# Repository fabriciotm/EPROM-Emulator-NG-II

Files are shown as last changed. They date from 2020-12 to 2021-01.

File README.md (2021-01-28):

# EPROM Emulator NG II

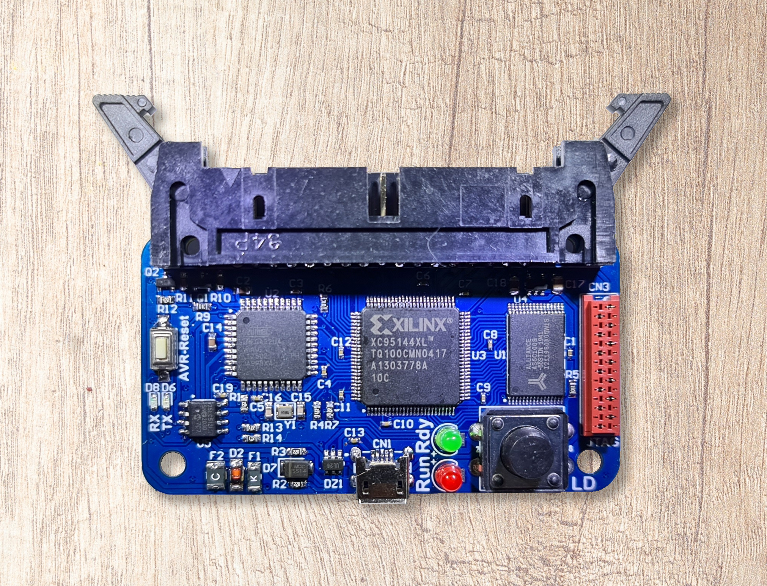
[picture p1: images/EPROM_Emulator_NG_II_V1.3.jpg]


## Introduction

Based on the project by Kris Sekula:

**GitHub**: https://github.com/Kris-Sekula/EPROM-EMU-NG

I developed a version where the TTL logic was replaced by a CPLD. This made the circuit much smaller. 

Instead of the Arduino Nano I directly integrated an ATMega32u4. This is flashed with the bootloader of the Arduino Micro (Using a simple ISP programmer). After that, the firmware can be flashed via USB at any time using the Arduino IDE.

## PCB

**PCB Version 1.3B**

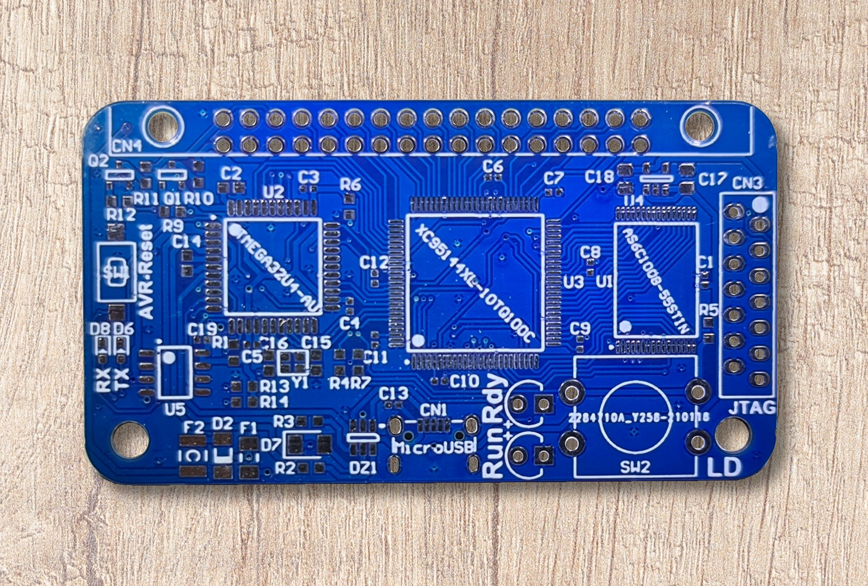
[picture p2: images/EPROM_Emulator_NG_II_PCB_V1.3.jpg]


Current version of the board.

## Assembly

The assembly is done from large to small. So first the biggest parts, like CPLD, ATMega, etc. are soldered on. Then in descending order the other parts, except the EEPROM. 

This should be soldered only after the bootloader for the ATMega has been flashed. Otherwise there can be problems with flashing.

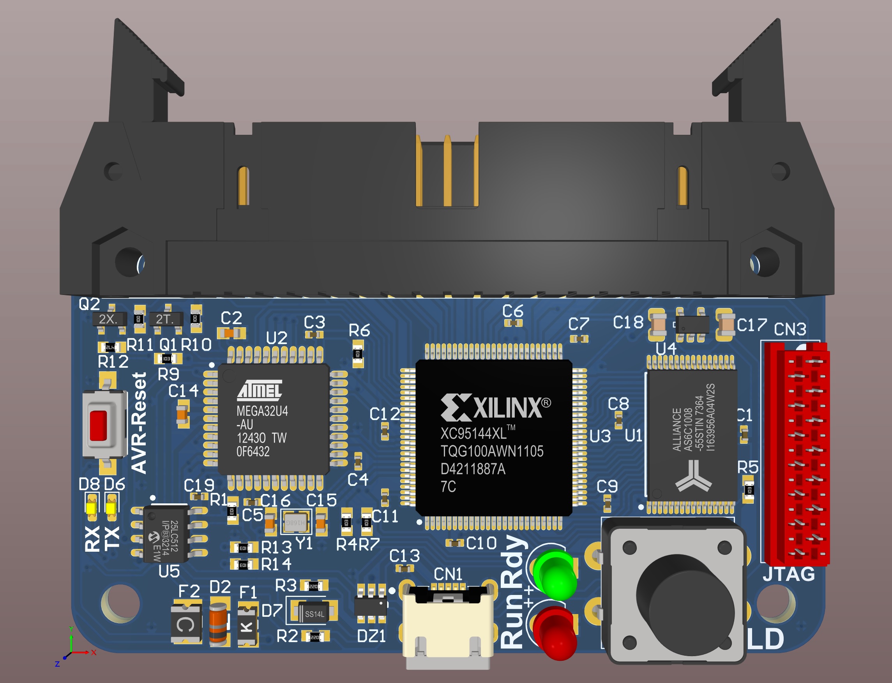
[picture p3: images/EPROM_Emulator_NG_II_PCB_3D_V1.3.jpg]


When all parts, except the EEPROM, are soldered, it goes to the flashing of the Arduino bootloader.

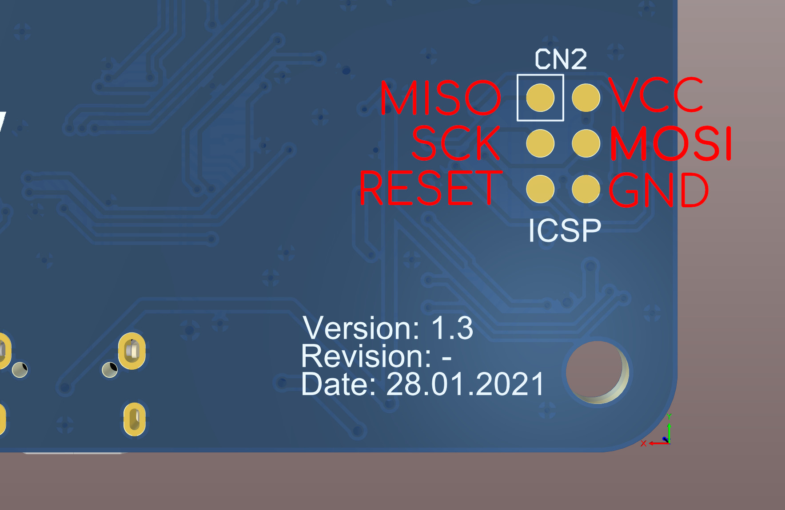
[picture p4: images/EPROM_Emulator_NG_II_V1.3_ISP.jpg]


For this purpose, there is a corresponding connector on the back. The easiest way to flash the bootloader is with Pogo PINs or a simple pin header, which are pressed onto the contacts.

A USBasp can be used for programming, for example.  And with the Arduino IDE the bootloader can then be uploaded.

It is important that the Arduino Micro is selected here.

If the bootloader has been installed successfully, the EEPROM can now be soldered on.

## Firmware flashing

First the EPROM Emulator NG II can be connected to the PC via USB. With the help of the Arduino IDE the ATMega is programmed first.

The current firmware can be found at https://github.com/Kris-Sekula/EPROM-EMU-NG/tree/master/Firmware.

After that the CPLD has to be programmed. This can be done most easily with a FT232H board. These adapters are available at AliExpress already around $8. And as software xc3sprog is used. This is the easiest and fastest way to flash the CPLD.

At https://github.com/1c3d1v3r/neatPLA/tree/master/programming you can find a practical instruction how to proceed.

Now the EPROM Emulator NG II is ready for use.

The software for operation and control can be downloaded from https://github.com/Kris-Sekula/EPROM-EMU-NG/tree/master/Software.

## BOM

| No#  | Designator | Part | Description |
| ---- | --- | --- | --- |
| 1 | U1 | Alliance Memory AS6C1008-55STIN | SRAM Memory, 1048576bit, 2.7  5.5 V, 55ns 32-Pin STSOP |
| 2 | U2 | ATMEL ATMEGA32U4-AU | MCU, 8BIT, MEGAAVR, 16MHZ, TQFP-44 |
| 3 | U3 | Xilinx XC95144XL-10TQ100C | IC CPLD 144MC 10NS 100TQFP |
| 4 | U4 | MaxLinear SPX5205M5-L-3-3/TR | LDO Regulator Pos 3.3V 0.15A 5-Pin SOT-23 T/R |
| 5 | U5 | Microchip 25LC512-I/SN | IC, SM, EEPROM, SERIAL, 512K, SOIC8 |
| 6 | Q1 | ON SEMICONDUCTOR MMBT4403LT1G | Bipolar (BJT) Single Transistor, PNP, General Purpose, SOT-23-3 |
| 7 | Q2 | ON SEMICONDUCTOR MMBT4401 | Bipolar (BJT) Single Transistor, NPN, General Purpose, SOT-23-3 |
| 8 | D2 | STMICROELECTRONICS TMMBAT48FILM | Small Signal Schottky Diode, MiniMELF |
| 9 | D3 | WÜRTH ELEKTRONIK 151033RS03000 | LED, 3MM,  RED, Pitch 2.54mm |
| 10 | D4 | WÜRTH ELEKTRONIK 151033GS03000 | LED, 3MM,  GREEN, Pitch 2.54mm |
| 11 | D6, D8 | WÜRTH ELEKTRONIK 150060YS55040 | LED YELLOW DIFFUSED 0603 SMD |
| 12 | D7 | MCC SS14FL-TP | DIODE SCHOTTKY 40V 1A DO221AC |
| 13 | DZ1 | STMICROELECTRONICS USBLC6-2SC6 | TVS DIODE 5.25V 17V SOT23-6 |
| 14 | Y1 | Raltron Electronics R2016-16.000-9-1010-TR-NS1 | 16MHz ±10ppm 9pF 200Ω SMD,2.0x1.6mm SMD Crystal |
| 15 | F1 | Littlefuse 1206L150THWR | PTC RESET FUSE 8V 1.5A 1206 |
| 16 | F2 | Littlefuse 1210L020WR | PPTC Resettable Fuse, SMD, POLYFUSE 1210L Series, 200 mA, 400 mA, 30 VDC |
| 17 | C1, C3-C13, C19 | Murata GRM155R71A104KA01 | 0.1µF ±10% 10V Ceramic Capacitor X7R 0402 (1005 Metric) |
| 18 | C2, C14 | KEMET C0603C105K3RACTU | 1F Multilayer Ceramic Capacitor (MLCC) 25 V 10% X7R dielectric C SMD max op. temp. +125C |
| 19 | C15, C16 | KEMET C0603C220J5RACTU | Cap Ceramic 22pF 50V X7R 5% SMD 0603 125°C Punched Paper T/R |
| 20 | C17, C18 | KEMET C0805C106K8RACTU | CAP, 10µF, 10V, 10%, X7R, 0805 |
| 21 | R1, R4, R7, R13, R14 | Yageo RC0603FR-071KL | RES SMD 1K OHM 1% 1/10W 0603 |
| 22 | R2, R3 | Yageo RC0603FR-0722RL | RES SMD 22 OHM 1% 1/10W 0603 |
| 23 | R5, R6, R9 | Yageo RC0603FR-0710KL | RES SMD 10K OHM 1% 1/10W 0603 |
| 24 | R10, R11 | Yageo RC0603FR-0710RL | RES SMD 10 OHM 1% 1/10W 0603 |
| 25 | R12 | Yageo RC0603FR-074K7L | RES SMD 4.7K OHM 1% 1/10W 0603 |
| 26 | CN1 | Würth Elektronik 629105150521 | Socket micro-USB B 5P |
| 27 | CN3 | MPE Garry 369-1-014-0-NTX-KT0 | Conn Wire to Board HDR 14 POS 1.27mm Solder ST Thru-Hole |
| 28 | CN4 | TE Connectivity AMP 5499345-8 | Conn Ejector Header HDR 34 POS 2.54mm Solder RA Thru-Hole |
| 29 | SW1 | ITT C&K RS-282G05A3-SMRT | SWITCH TACTILE SPST-NO 0.05A 12V |
| 30 | SW2 | Würth Electronics 430476085716 | Black Button Tactile Switch, NO 50 mA 5mm Through Hole |

## PCB

The PCB can either be ordered directly from [PCBWay](https://www.pcbway.com/project/shareproject/EPROM_Emulator_NG_II.html), or you can create it yourself from the Gerber files available here.

PCBWay (https://www.pcbway.com/project/shareproject/EPROM_Emulator_NG_II.html)

If you liked my project, I would be very happy about a small coffee donation.



## License

The content of this repository, except for the Arduino code is released under the following license:

- the "Creative Commons Attribution-NonCommercial-ShareAlike 4.0 International License" (CC BY-NC-SA 4.0) full text of this license is included in the [LICENSE.CC-NC-BY-SA-4.0](https://github.com/DL2DW/EPROM-Emulator-NG-II/blob/main/LICENSE.CC-NC-BY-SA) file and a copy can also be found at https://creativecommons.org/licenses/by-nc-sa/4.0/

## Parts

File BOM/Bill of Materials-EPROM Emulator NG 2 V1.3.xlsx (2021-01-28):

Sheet: Part List Report
 | Component list |  |  | Bill of Materials for Project [EPROM Emulator NG 2.PrjPcb] (PCB Document : EPROM Emulator NG 2.PcbDoc)
 | Source Data From: | EPROM Emulator NG 2.PrjPcb |  |  | Contact: |  |  |  | Generated by:
 | Project: | EPROM Emulator NG 2.PrjPcb |  |  | <Parameter ClientCompanyName not found>
 | Variant: | None |  |  | <Parameter ClientContactName not found>
 |  |  |  |  | <Parameter ClientContactEmail not found>
 | Report Date: | 17.01.2021 | 09:32 |  | <Parameter ClientWebsite not found>
 | Print Date: | 2021-01-17 | 9:32:20
# | #Column Name Error:' Category | Manufacturer 1 | Manufacturer Part Number 1 | Case/Package | Description | Quantity | Supplier 1 | Supplier Part Number 1 | Supplier Order Qty 1 | Supplier Stock 1 | Supplier Unit Price 1 | Supplier Subtotal 1 | Supplier Currency 1
1 |  | Raltron Electronics | R2016-16.000-9-1010-TR-NS1 |  | 16MHz ±10ppm 9pF 200Ω SMD,2.0x1.6mm SMD Crystal Resonators RoHS | 1 | Digi-Key | 2151-R2016-16.000-9-1010-TR-NS1CT-ND |  | 2990
2 |  | KEMET | C0603C220J5RACTU | 603 | 22.0PF 50.0V | 2 | Farnell | 2821146 |  | 5639 |  |  | EUR
3 |  | Alliance Memory | AS6C1008-55STIN | TSOP | Alliance Memory AS6C1008-55STIN SRAM Memory, 1048576bit, 2.7 5.5 V, 55ns 32-Pin STSOP | 1 | Digi-Key | 1450-1019-ND |  | 234
4 |  | Microchip / Atmel | ATMEGA32U4-AU | TQFP | ATMEL ATMEGA32U4-AU MCU, 8BIT, MEGAAVR, 16MHZ, TQFP-44 | 1 | Farnell | 1748525 | 1 | 1060 | 3.66 | 3.66 | EUR
5 |  | Wurth Electronics | 430476085716 |  | Black Button Tactile Switch, NO 50 mA 5mm Through Hole | 1 | Element14 | 2402379 |  | 548
6 |  | Murata | GRM155R71A104KA01D | 402 | CAP CER 0.1UF 10V X7R 0402 | 13 | Element14 | 1828860 |  | 0
7 |  | TE Connectivity AMP | 5499345-8 |  | Conn Ejector Header HDR 34 POS 2.54mm Solder RA Thru-Hole Loose Piece | 1 | Farnell | 3165146 |  | 0 |  |  | EUR
8 |  | MCC | SS14FL-TP |  | DIODE SCHOTTKY 40V 1A DO221AC | 1 | Mouser | 833-SS14FL-TP |  | 0
9 |  | MPE-Garry | 369-1-014-0-NTX-KT0 |  | Grid pitch: 1.27 mm BL2/15-0400GTT-014 RU MPE Garry Conten | 1 | Schukat | BL215400-14 |  | 1050 |  |  | EUR
10 |  | Xilinx | XC95144XL-7TQ100C | LQFP | IC CPLD 144MC 7.5NS 100TQFP | 1 | Digi-Key | 122-1252-ND |  | 0
11 |  | Microchip | 25LC512-I/SN | SOIC | IC, SM, EEPROM, SERIAL, 512K, SOIC8 | 1 | Farnell | 1556153 | 1 | 3865 | 1.56 | 1.56 | EUR
12 |  | KEMET | C0603C105K3RACTU | 603 | KEMET 1F Multilayer Ceramic Capacitor (MLCC) 25 V 10% X7R dielectric C SMD max op. temp. +125C | 2 | Farnell | 2118128 |  | 63584 |  |  | EUR
13 |  | KEMET | C0805C106K8RACTU | 805 | KEMET - C0805C106K8RACTU - CAP, 10µF, 10V, 10%, X7R, 0805 | 2 | Element14 | 2118132 |  | 29727
14 |  | Exar | SPX5205M5-L-3-3/TR | SOT-23 | LDO Regulator Pos 3.3V 0.15A 5-Pin SOT-23 T/R | 1 | Farnell | 2889628 |  | 22 |  |  | EUR
15 |  | Wurth Electronics | 150060YS55040 | 603 | LED YELLOW DIFFUSED 0603 SMD | 2 | Element14 | 2900767 |  | 3535
16 |  | Littelfuse | 1210L020WR | 1210 | LITTELFUSE - 1210L020WR - PPTC Resettable Fuse, SMD, POLYFUSE 1210L Series, 200 mA, 400 mA, 30 VDC, -40 °C | 1 | TME | 1210L020WR |  | 681
17 |  | ON Semiconductor / Fairchild | MMBT4401 | SOT-23 | ON SEMICONDUCTOR - MMBT4401 - TRANSISTOR, NPN, SMD, SOT-23 | 1 | Element14 | 1467898 |  | 0
18 |  | ON Semiconductor | MMBT4403LT1G | SOT-23-3 | ON SEMICONDUCTOR - MMBT4403LT1G - Bipolar (BJT) Single Transistor, General Purpose, PNP, -40 V, 200 MHz, 300 mW, -600 mA, 200 RoHS Compliant: Yes | 1 | Element14 | 1653705 |  | 66402
19 |  | Littelfuse | 1206L150THWR | 1206 | PTC RESET FUSE 8V 1.5A 1206 | 1 | TME | 1206L150THWR |  | 3000
20 |  | Yageo | RC0603FR-071KL | 603 | RES SMD 1K OHM 1% 1/10W 0603 | 5 | Farnell | 1117234 |  | 0
21 |  | Yageo | RC0603FR-074K7L | 603 | RES SMD 4.7K OHM 1% 1/10W 0603 | 1 | Farnell | 1117265 |  | 0
22 |  | Yageo | RC0603FR-0710KL | 603 | RES SMD 10K OHM 1% 1/10W 0603 | 3 | Element14 | 1117235 |  | 0
23 |  | Yageo | RC0603FR-0722RL | 603 | RES SMD 22 OHM 1% 1/10W 0603 | 2 | Farnell | 1117255 |  | 0
24 |  |  |  |  | SMD Pad Connector 02x03 odd even | 1
25 |  | Wurth Electronics | 629105150521 |  | Socket micro-USB B 5P, 629105150521, Würth Elektronik | 1 | Conrad | 1898830 | 1 | -2 | 2.19 | 2.19 | EUR
26 |  | STMicroelectronics | TMMBAT48FILM | MELF | STMICROELECTRONICS TMMBAT48FILM.. Small Signal Schottky Diode, Single, 40 V, 350 mA, 900 mV, 7.5 A, 125 C | 1 | Element14 | 1467570 |  | 22858
27 |  | ITT C&K | RS-282G05A3-SMRT |  | SWITCH TACTILE SPST-NO 0.05A 12V | 1 | Farnell | 3263270 |  | 0 |  |  | EUR
28 |  | STMicroelectronics | USBLC6-2SC6 | SOT-23 | TVS DIODE 5.25V 17V SOT23-6 | 1 | Farnell | 1269406 |  | 34294 |  |  | EUR
29 |  | Wurth Electronics | 151033GS03000 | Radial | WURTH ELEKTRONIK - 151033GS03000 - LED, Green, T-1 (3mm), 530 nm, 3.2 V, 30 mA, 15 cd RoHS Compliant: Yes | 1 | Farnell | 2322118 |  | 0 |  |  | EUR
30 |  | Wurth Electronics | 151033RS03000 | Radial | WURTH ELEKTRONIK 151033RS03000 LED, 3MM, RED, 2600MCD, 621NM | 1 | Farnell | 2322116 |  | 791 |  |  | EUR
31 |  |  |  | 603 | YAGEO (PHYCOMP) - RC0603FR-0710RL - RES, THICK FILM, 10R, 1%, 0.1W, 0603 | 2
 |  |  |  |  |  | 55 |  |  | 3 |  |  | 7.41
Approved |  |  |  | Notes
 |  |  |  |  |  | 1 | pcs: | Total |  | 7.41 |  | USD
 |  |  |  |  |  |  |  | Price for 1pcs |  | 7.41 |  | USD

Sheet: Project Information
Project Full Path | D:\Elektronik\Altium\Projects\EPROM Emulator NG 2\EPROM Emulator NG 2.PrjPcb
Project Filename | EPROM Emulator NG 2.PrjPcb
Variant Name | None
Data-Source Filename | EPROM Emulator NG 2.PrjPcb
Data-Source Full Path | D:\Elektronik\Altium\Projects\EPROM Emulator NG 2\EPROM Emulator NG 2.PrjPcb
Title | Bill of Materials for Project [EPROM Emulator NG 2.PrjPcb] (PCB Document : EPROM Emulator NG 2.PcbDoc)
Total Quantity | 55
Report Time | 09:32
Report Date | 17.01.2021
Report Date & Tine | 17.01.2021 09:32
Output Name | Bill of Materials
Output Type | BOM_PartType
Output Generator Name | BOM
Output Generator Description | Bill of Materials

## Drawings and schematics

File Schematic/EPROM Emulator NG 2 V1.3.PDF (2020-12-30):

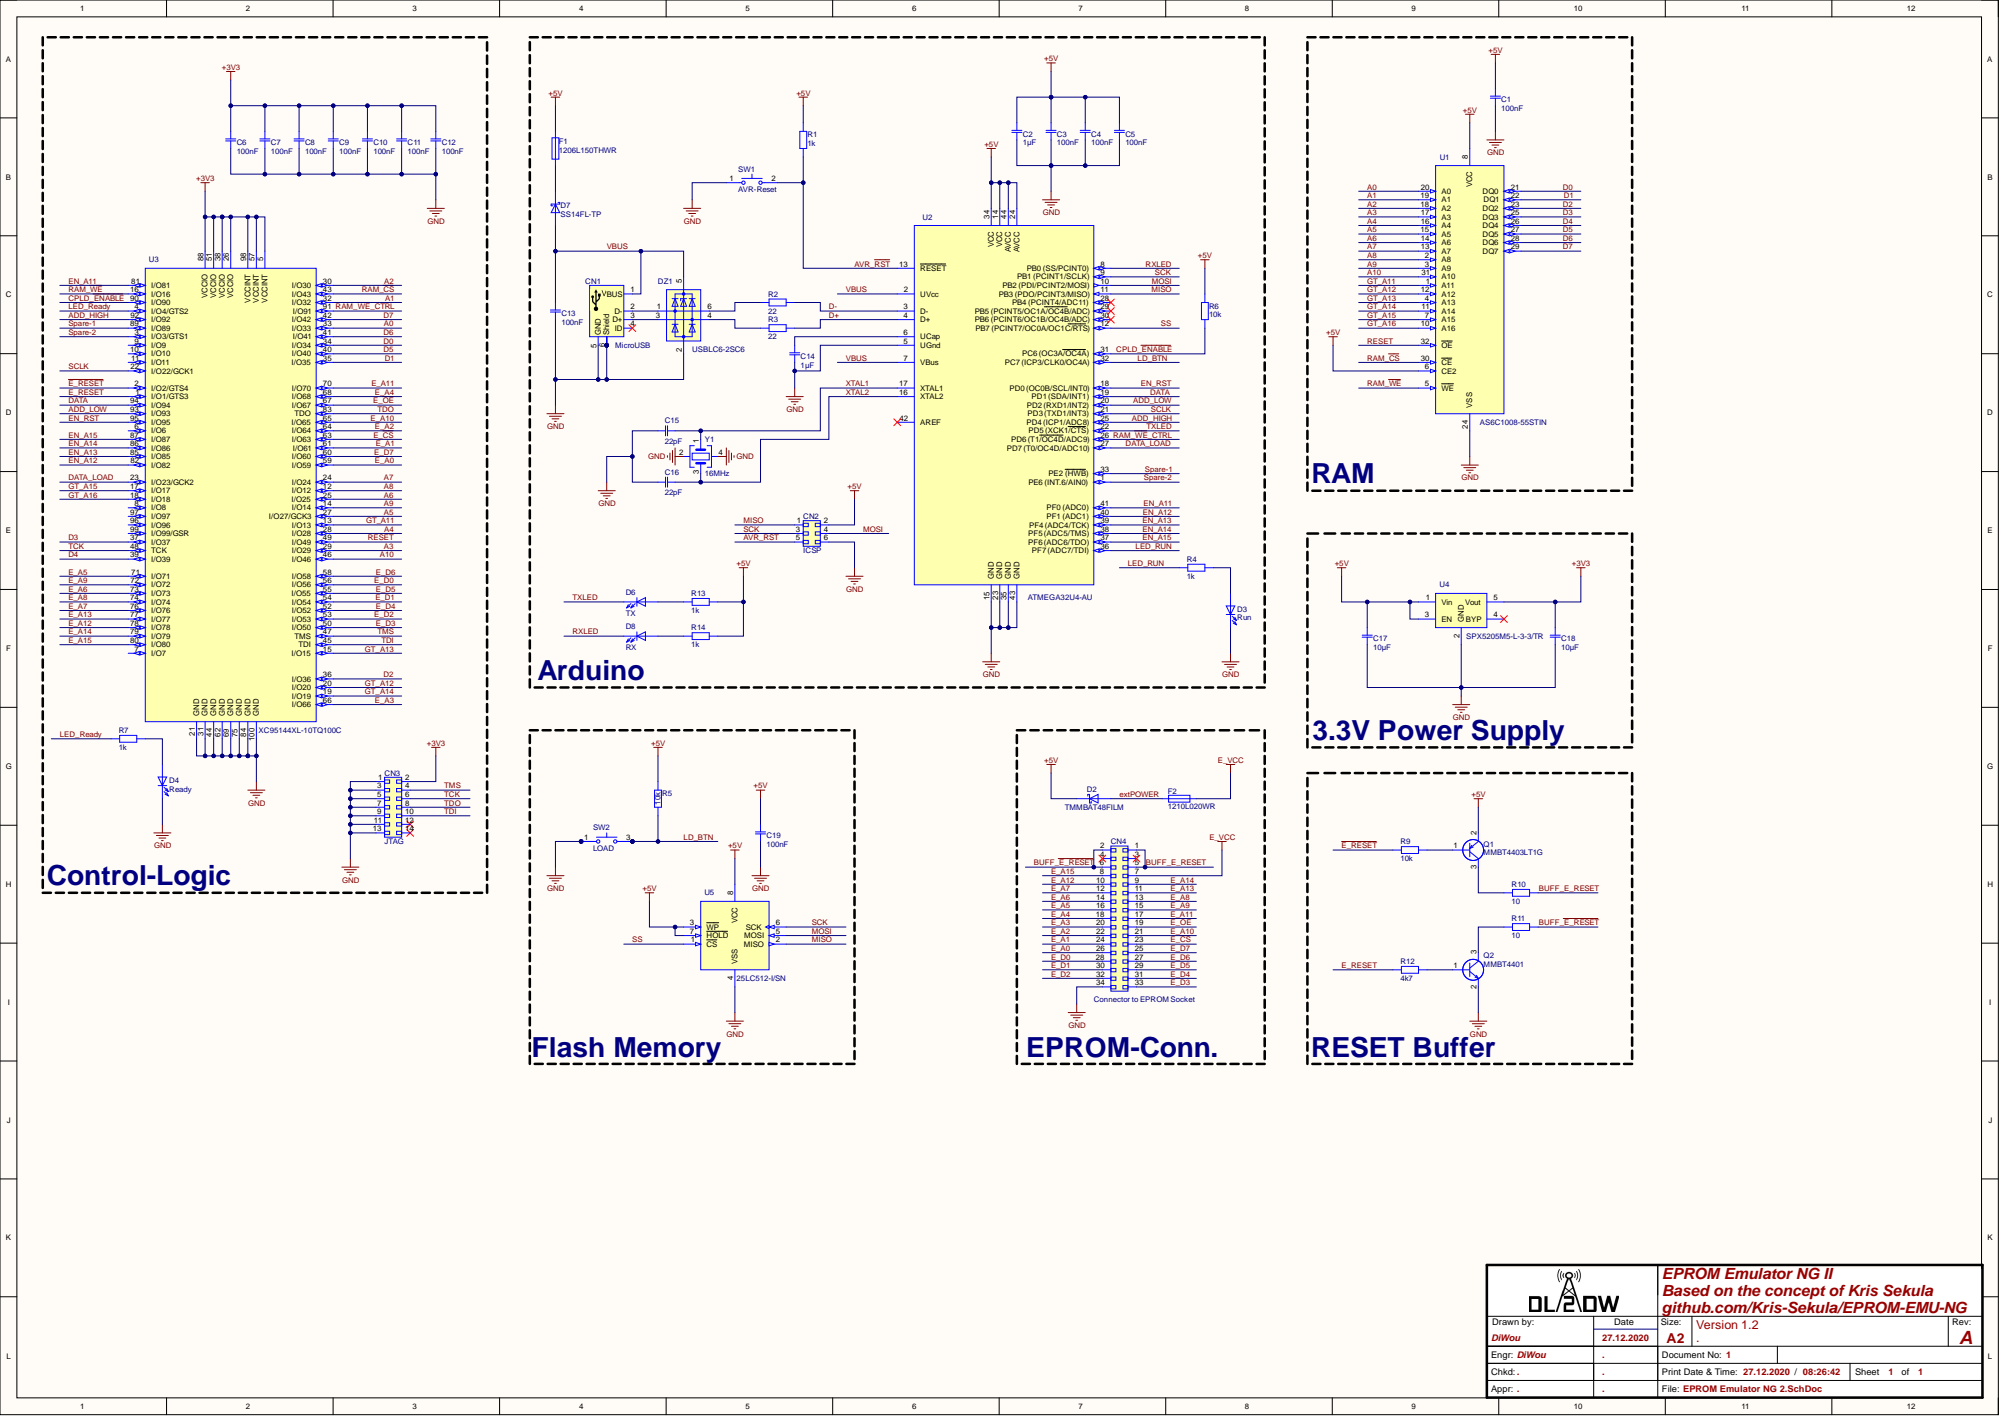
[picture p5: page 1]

C 2 | C 3 | C 4
1 µ F | 100n F | 100n F

EPROM Emulator NG II
Based on the concept of Kris Sekula
github.com/Kris-Sekula/EPROM-
Size: File:

Engr : DiWo u | .. | Document No: 1

Chkd: . | | P rint Date & Time: 27.12.202 0 / 08:26: 4 2 | Sheet 1 of 1

Appr : . | . | E PROM E m ulat o r NG 2.SchDo c

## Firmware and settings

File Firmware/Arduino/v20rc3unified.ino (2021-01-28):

//
// this sketch controls the EPROM memory Emulator hardware described on mygeekyhobby.com
//
// 1.8rc1 Oct-2020
//  - optimized for speed (now loading from SPI via a button or "auto" takes only 3.5s for 27512)
//  - HW version now in EEPROM of the Arduino, so doesn't change every time you upload a new sketch version (update the default HW version below before you run the first time)
//  - only update "last EPROM" if Save to SPI was on... this way when you reload from SPI EEPROM you will also get the last used EPROM type configured on the bus (this was a bug before)
//  - includes the fix as per ERRATA for PCB ver 1.6 and below
//
// 2.0rc1 Oct-2020
//  - support for binary transfer
//  - support for SPI EEPROM addressed transfers
//
// 2.0rc1ultrafast2 2020-12-10
//  - Fast/Ultrafast version by Hubert H.
//  - some fixes
//  - double SPI clock (f/2)
//  - Speed optimizations im SRAM loading
//  - Compile option for unfixed older boards
//
// 2.0rc1ultrafast3 2020-12-14
//  - Ultrafast version by Hubert H.
//  - Ultrafst only, removed Fast Option
//
// 2.0rc3
//  - change the "long-press" LOAD button function from "disable auto-load" to more useful "reset target" function
//
// 2.0rc3update1 by Ralf-Peter Nerlich (aka Hubert H.) <early8bitz.de>
//  - remove unused variable 'page_ctn'
//  - move variable 'spi_address' from global scope to function load_SPIEEPROM()
//      The variable is only used in this function.
//      The positive side effect: Saves 20ms more in loading SRAM
//  - simplify filling shift registers in writeMemoryLocation(), two variables are omitted.
//      No effect on speed.
//  - in long press button move the turn LED off few lines up, so the 150ms is included in LED off time
//      This makes it easier to recognize the triggering of the reset and release the button at the right time

// 2.0rc3unified by Ralf-Peter Nerlich (aka Hubert H.) <early8bitz.de>
//  - Variants for original PCB (Kris Sekula) and Dirk Wouters PCB
//  - Code for power down of unused Parts in MCU (experimental)

#include <EEPROM.h>
#include <util/atomic.h>
#include <avr/power.h>

#undef UNFIXED
//#undef DW32U4
// For using with the original PCB from Kris Sekula (Arduino Nano, ATmega328p) leave DW32U4 undefined
// For using with the new PCB from Dirk Wouters (ATmega32u4) please enable the following line
#define DW32U4

#ifndef DW32U4
//
// Begin definitions for original PCB (Kris Sekula)
//
// Software Fix for original boards with SRAM /OE=GND (<= v1.6 without fix)
// For unfixed Bords enable the following line
//#define UNFIXED

// Signals to shift register 74HC595
#define DATA     (3) // data pin for shift register handling D0-D7
#define ADLO     (4) // data pin for shift register handling A0-A7
#define ADHI     (5) // data pin for shift register handling A8-A15
#define SCLK     (7) // clock ping for all shift registers
#define DAT_LD   (6) // latch pin for all shift registers 

// Bits for direct port access to shift register
#define DATAPORT PORTD
#define DATABIT  (3) //PORTD:3
#define ADLOPORT PORTD
#define ADLOBIT  (4) //PORTD:4
#define ADHIPORT PORTD
#define ADHIBIT  (5) //PORTD:5
#define SCLKPORT PORTD
#define SCLKBIT  (7) //PORTD:7
#define DATLDPORT PORTD
#define DATLDBIT (6) //PORTD:6

// Signals to SRAM
#define WE       (8) // SRAM Write Enable Pin

// Bits for direct port access to SRAM
#define WEPORT PORTB
#define WEBIT    (0) //PORTB:0

// Other signals
#define EN_RST (2)   //  internal / external bus control pin
#define LD_BTN (9)   // load data from SPI button
#define LED_G (A0)   // RED LED

// Bits for direct port access to LED_G
#define LEDPIN PINC
#define LEDBIT    (0) // PORTC:0

// Gating signals - ignores selected A11 - A15 address pins besed on EPROM Type
#define EN_A11 (A1)  // A11 data pin gating signal 
#define EN_A12 (A2)  // A12 data pin gating signal 
#define EN_A13 (A3)  // A13 data pin gating signal 
#define EN_A14 (A4)  // A14 data pin gating signal 
#define EN_A15 (A5)  // A15 data pin gating signal 

// SPI EEPROM stuff (using default SPI pins)
#define DATAOUT   MOSI  // 11
#define DATAIN    MISO  // 12
#define SPICLOCK   SCK  // 13
#define SLAVESELECT SS  // 10
//
// End definitions for original PCB (Kris Sekula)
//
#else
//
// Begin definitions for new PCB (Dirk Wouters)
//
// Signals to shift register 74HC595
#define DATA     (2)  // data pin for shift register handling D0-D7
#define ADLO     (0)  // data pin for shift register handling A0-A7
#define ADHI     (4)  // data pin for shift register handling A8-A15
#define SCLK     (1)  // clock ping for all shift registers
#define DAT_LD   (6)  // latch pin for all shift registers 

// Bits for direct port access to shift register
#define DATAPORT PORTD
#define DATABIT  (1)  //PORTD:1
#define ADLOPORT PORTD
#define ADLOBIT  (2)  //PORTD:2
#define ADHIPORT PORTD
#define ADHIBIT  (4)  //PORTD:4
#define SCLKPORT PORTD
#define SCLKBIT  (3)  //PORTD:3
#define DATLDPORT PORTD
#define DATLDBIT (7)  //PORTD:7

// Signals to SRAM
#define WE       (12) // SRAM Write Enable Pin

// Bits for direct port access to SRAM
#define WEPORT PORTD
#define WEBIT    (6)  //PORTD:6

// Other signals
#define EN_RST   (3)  //  internal / external bus control pin
#define LD_BTN  (13)  // load data from SPI button
#define LED_G   (A0)  // RED LED
#define EN_CPLD  (5)  // CPLD enable signal

// Bits for direct port access to LED_G
#define LEDPIN PINF
#define LEDBIT    (7) // PORTF:7

// Gating signals - ignores selected A11 - A15 address pins besed on EPROM Type
#define EN_A11 (A5)   // A11 data pin gating signal 
#define EN_A12 (A4)   // A12 data pin gating signal 
#define EN_A13 (A3)   // A13 data pin gating signal 
#define EN_A14 (A2)   // A14 data pin gating signal 
#define EN_A15 (A1)   // A15 data pin gating signal 

// SPI EEPROM stuff (using default SPI pins except SS)
#define DATAOUT   MOSI  // 16
#define DATAIN    MISO  // 14
#define SPICLOCK   SCK  // 15
#define SLAVESELECT (11)
//
//end definitions for new PCB (Dirk Wouters)
//
#endif

// SPI opcodes - taken from Arduino SPI examples
#define WREN  (6)
#define WRDI  (4)
#define RDSR  (5)
#define WRSR  (1)
#define READ  (3)
#define WRITE (2)
#define CE    (0xc7)  // SPI_EEPROM Chip erase (1100 0111)

// Page & buffer sizes
#define PAGESIZE (128)  // Size of page operations in EEPROM 25LC512
#define BBUFSIZE (512)  // Transferbuffersize

// utility byte
byte clr;

// binary transfer buffer
byte byteBuffer [BBUFSIZE + 1];

enum {noROM, rom2kB, rom4kB, rom8kB, rom16kB, rom32kB, rom64kB, lastType};

// configuration addresses in internal EEPROM - use either enumeration or constant variables
enum {mem_cfg, save_cfg, auto_cfg, sram_cfg, ver_cfg = 10};
//const int mem_cfg = 0;  // EEPROM address where we store last used EPROM type (value 1 = 2716, 2 = 2732, 3 = 2764, 4 = 27128, 5 = 27256, 6 = 27512)
//const int save_cfg = 1; // EEPROM address where we store settings for "SAVE to SPI EEPROM option" (value 1 = yes, 0 = no)
//const int auto_cfg = 2; // EEPROM address where we store settings for "Auto load from SPI EEPROM" option (value 1 = yes, 0 = no)
//const int sram_cfg = 3; // EEPROM address where we store last EPROM type loaded in SRAM
//const int ver_cfg = 10; // EEPROM start addres where we store hardware version (up to 10 characters)

// global config settings
bool saveSPI;
bool autoLoad;
unsigned int lastEPROM;

const char FW_ver[] = "2.0rc3";
char HW_ver[10];

// Name strings for romTypes (same order as in enumeration)
const char* memTable[lastType] = {"invalid", "2716", "2732", "2764", "27128", "27256", "27512"}; // lookup table for memory type

void setup() {

  power_adc_disable();        // Power down unneeded parts in MCU (https://www.gammon.com.au/power)
  power_twi_disable();
  power_timer1_disable();
  power_timer2_disable();

  // Initialize all pins
#ifdef DW32U4
  // After MCU reset /EN_CPLD is in INPUT mode and therefore floating (but should be pulled to HIGH with an external resistor)
  pinMode( EN_CPLD, INPUT_PULLUP); // activates the internal pullup and prepares the pin for immediately HIGH when it is set to OUTPUT mode
  pinMode( EN_CPLD, OUTPUT );      // now /EN_CPLD is OUTPUT and active HIGH
#endif
#ifdef UNFIXED
  pinMode( EN_RST, OUTPUT ); digitalWrite( EN_RST, LOW );  // disable outputs to start with AD0-15 from outside
#else
  // At power on, SRAM is undefined. We must fill it first.
  // So we start with holding target in RESET,
  // disabled 541 buffers and enabled shift registers
  // After MCU reset EN_RST is in INPUT mode and therefore floating
  //    but should be pulled to HIGH with an external resistor (Kris)
  //    or should be gated in CPLD (Dirk)
  pinMode( EN_RST, INPUT_PULLUP);  // activates the internal pullup and prepares the pin for immediately HIGH when it is set to OUTPUT mode
  pinMode( EN_RST, OUTPUT );       // now EN_RST is OUTPUT and active HIGH
#endif
  // After MCU reset /WE is in INPUT mode and therefore floating
  //    but should be pulled to HIGH with an external resistor (Kris)
  //    or should be gated in CPLD (Dirk)
  pinMode( WE, INPUT_PULLUP);      // activates the internal pullup and prepares the pin for immediately HIGH when it is set to OUTPUT mode
  pinMode( WE, OUTPUT );           // now /WE is OUTPUT and active HIGH
  pinMode( LED_G, OUTPUT ); digitalWrite( LED_G, LOW );

  pinMode( DATA, OUTPUT ); digitalWrite( DATA, LOW );
  pinMode( ADLO, OUTPUT ); digitalWrite( ADLO, LOW );
  pinMode( ADHI, OUTPUT ); digitalWrite( ADHI, LOW );

  pinMode( DAT_LD, OUTPUT ); digitalWrite( DAT_LD, LOW );
  pinMode( SCLK, OUTPUT ); digitalWrite( SCLK, LOW );

  // address lines gate signals as outputs
  pinMode( EN_A11, OUTPUT );
  pinMode( EN_A12, OUTPUT );
  pinMode( EN_A13, OUTPUT );
  pinMode( EN_A14, OUTPUT );
  pinMode( EN_A15, OUTPUT );

  setBus(rom64kB); //  default settings to enable all address lines

  pinMode(LD_BTN, INPUT_PULLUP);  // Force High if runs on Arduino without PCB

#ifdef DW32U4
  // Now all digital pins controlling the emulation in their initialized state
  // We can release the CPLD chip
  digitalWrite(EN_CPLD, LOW);
#endif

  // SPI EEPROM pins
  pinMode(DATAOUT, OUTPUT);
  pinMode(DATAIN, INPUT);
  pinMode(SPICLOCK, OUTPUT);
  pinMode(SLAVESELECT, OUTPUT); digitalWrite(SLAVESELECT, HIGH); //disable device

  // SPCR = 01010000; SPSR = 00000001
  //interrupt disabled,spi enabled,msb 1st,master,clk low when idle,
  //sample on leading edge of clk,system clock/2 rate (fastest)
  //results in 8MHz SPI clock. 25LC512 supports at least 10MHz.
  ATOMIC_BLOCK(ATOMIC_FORCEON) {
    SPCR = (1 << SPE) | (1 << MSTR);
    SPSR = (1 << SPI2X);
  } // end ATOMIC
  clr = SPSR;
  clr = SPDR;
  //
  Serial.begin(115200);

  //clearSPIEEPROM(); // one time only erase EEPROM

  // load configuration, set defaults if needed

  //
  // Set default config values if config EEPROM contains invalid values
  // Should only occur during the very first start uf program
  //
  if ((EEPROM.read(mem_cfg) > rom64kB) || (EEPROM.read(mem_cfg) < rom2kB)) {
    EEPROM.update(mem_cfg, rom64kB);
    Serial.println(F("Setting default EPROM Memory to 27512"));
  }
  if ((EEPROM.read(sram_cfg) > rom64kB) || (EEPROM.read(sram_cfg) < rom2kB)) {
    lastEPROM = rom64kB;
    EEPROM.update(sram_cfg, rom64kB);
    Serial.println(F("Setting default SRAM Memory to 27512"));
  }
  else {  // sram_cfg is valid
    lastEPROM = EEPROM.read(sram_cfg) ;
    Serial.println(String(F("Config: Last EPROM used from SRAM is ")) + memTable[lastEPROM]);
    Serial.println(String(F("Config: Last EPROM stored in SPI is  ")) + memTable[EEPROM.read(mem_cfg)]);
  }
  //
  // get "save to SPI_EEPROM" config from EEPROM
  //
  switch (EEPROM.read(save_cfg)) {
    case 0:
      saveSPI = false;
      Serial.println(F("Option: Save to SPI EEPROM set to disable"));
      break;
    case 1:
      saveSPI = true;
      Serial.println(F("Option: Save to SPI EEPROM set to enable"));
      break;
    default:
      saveSPI = false;
      EEPROM.update(save_cfg, 0);
      Serial.println(F("Default: disabling save to spi"));
      break;
  }
  //
  // get "auto load from SPI_EEPROM" config from EEPROM
  //
  switch (EEPROM.read(auto_cfg)) {
    case 0:
      autoLoad = false;
      Serial.println(F("Option: Auto load from SPI EEPROM set to disable"));
      break;
    case 1:
      autoLoad = true;
      Serial.println(F("Option: Auto load from SPI EEPROM set to enable"));
      break;
    default:
      autoLoad = false;
      EEPROM.update(auto_cfg, 0);
      Serial.println(F("Default: Disabling Auto load from SPI EEPROM "));
      break;
  }

  // load data from SPI EEPROM if configured

  if (autoLoad) {  // we use the SPI stored image and start emulation
    lastEPROM = EEPROM.read(mem_cfg);
    load_SPIEEPROM(lastEPROM);  // Fills the SRAM from SPI, setBus() and release the target RESET (start emulation)
  } else {         // we use the last in SRAM stored image and remain in reset
    setBus(lastEPROM);
  }

  //
  // get hardware version from EEPROM
  //
  EEPROM.get(ver_cfg, HW_ver); // load version from EEPROM

  if (HW_ver[0] != 'v') {
    // set default version
    Serial.println(F("setting default internal hw version"));
    //
    EEPROM.put(ver_cfg, "v1.7"); //Set this to whatever you have on the PCB, if you did the HW mod as per Errata, call it v1.6f or similar   <--------- README
    EEPROM.get(ver_cfg, HW_ver);
  }
  //
  // if you missed setting up the hw version before, you can temporary replace the "if((HW_ver[0] != 'v')" with "if(1)"
  //

  Serial.println(F("\nEmulator Started, waiting for computer contol"));
  printabout();
} // end setup()

//
// restore SRAM from SPI EEPROM
//
void load_SPIEEPROM (unsigned int eprom) {

  register word spi_address = 0;  // SPI_EEPROM address
  unsigned long time = millis(); // Start time measurement
  setBus(rom64kB);              // allows access to entire 64kb SRAM Memory - equivlet of emulating 27512 eprom
#ifdef UNFIXED
  digitalWrite( WE, LOW);       // brings data bus of SRAM to high-z (only unmodified 1.6 boards)
#endif
  digitalWrite( EN_RST, HIGH ); // reset target, disable 541 buffers, enable shift registers
  digitalWrite( LED_G, LOW );

  unsigned int maxPage;
  // Calculate number of pages: #pages = eprom_size / PAGESIZE
  switch (eprom) {
    case rom2kB:
      maxPage = (1L << 11) / PAGESIZE; // A0..A10 16kb/2kB
      break;
    case rom4kB:
      maxPage = (1L << 12) / PAGESIZE; // A0..A11 32kb/4kB
      break;
    case rom8kB:
      maxPage = (1L << 13) / PAGESIZE; // A0..A12 64kb/8kB
      break;
    case rom16kB:
      maxPage = (1L << 14) / PAGESIZE; // A0..A13 128kb/16kB
      break;
    case rom32kB:
      maxPage = (1L << 15) / PAGESIZE; // A0..A14 256kb/32kB
      break;
    case rom64kB:
      maxPage = (1L << 16) / PAGESIZE; // A0..A15 512kb/64kB
      break;
    default:
      Serial.print(F( "-> Default: "));
      maxPage = (1L << 16) / PAGESIZE; // A0..A15 512kb/64kB
      break;
  }
  Serial.println(String(F("-> Loading ")) + memTable[eprom] + String(F(" EPROM from SPI")));

  // now load this many pages from SPI EEPROM

  int clmn = 1;

  for ( unsigned int page = 0; page < maxPage; page++) {
    if (spi_address & 00010000) {   // flash LED while loading
      LEDPIN = 1 << LEDBIT;         // Toogle bit on pin A0 (by writing 1 in PINC:0 register)
    }

    digitalWrite(SLAVESELECT, LOW);      // select SPI EEPROM
    spi_transfer(READ);                     //transmit read opcode
    spi_transfer((byte)(spi_address >> 8)); //send MSByte address first
    spi_transfer((byte)(spi_address));      //send LSByte address

    for (int i = 0; i < PAGESIZE; i++) {
      SPDR = 0;                        // Start the transmission, clear pending SPIF flag
      while (!(SPSR & (1 << SPIF))) {} // Wait for the end of the transmission (SPIF is set)
      writeMemoryLocation(spi_address++, SPDR);  // get received byte and write it to SRAM, clear SPIF flag
    }
    digitalWrite(SLAVESELECT, HIGH);   //release chip, signal end transfer
    Serial.write('.');
    if (++clmn > 64) {
      Serial.write('\n');
      clmn = 1;
    }
  }
  Serial.write('\n');

  EEPROM.update(sram_cfg, eprom);  // After load from SPI, SRAM and SPI is the same ROM type (sram_cfg = mem_cfg)
  setBus(eprom);                   // now that SRAM is loaded with data, we can enable correct address lines
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
void loop() {

  if (digitalRead(LD_BTN) == LOW) {     // Yeah, the button is pressed
    delay(500);                         // Wait 0.5s and look again
    if (digitalRead(LD_BTN) == HIGH) {  // Button released after 500ms = short press
      // short press will load from SPI_EEPROM
      Serial.println(F("Load from SPI EEPROM triggered by pushbutton"));
      lastEPROM = EEPROM.read(mem_cfg);
      load_SPIEEPROM(lastEPROM);
    } else {                             // Button not released after 500ms
      delay(1000);                       // Wait 1s more
      if (digitalRead(LD_BTN) == LOW) {  // Button not released after (500+1000)ms = long press
        // long press resets target
        digitalWrite( LED_G, LOW );      // turn the LED off to indicate the RESET was initiated
        digitalWrite( EN_RST, HIGH);
        delay(150);
        digitalWrite( EN_RST, LOW );
        Serial.println(F("-> Resetting target via button"));
        while (digitalRead(LD_BTN) == LOW) {
          delay(100);                    // wait for releasing button
        }
        digitalWrite( LED_G, HIGH );    //
      }
    }
    delay(3000);                         // next possible push in 3s

  } // end processing push button

  if (Serial.available() > 0) {
    char ch = Serial.read();
    if ( ch == 0x0D /*CR*/) {
      return;
    }
    // detect end of frame
    if ( ch == 0x0A /*LF*/) {
      // decode frame

      //
      // get sync or stop emulation (like :EMUOFF)
      //
      if ( rxFrame == ":dml" ) {
#ifdef UNFIXED
        digitalWrite( WE, LOW);       // brings data bus of SRAM to high-z (only unmodified 1.6 boards)
#endif
        digitalWrite( EN_RST, HIGH ); // reset target, disable 541 buffers, enable shift registers
        digitalWrite( LED_G, LOW );   // RUN LED off
        printabout();
      }
      //
      // start emulation
      //
      if ( rxFrame == ":EMUON" ) {
#ifdef UNFIXED
        digitalWrite( WE, HIGH);      // enable SRAM outputs
#endif
        digitalWrite( EN_RST, LOW );  // disable shift registers, address enable buffers.
        digitalWrite( LED_G, HIGH );  // turn on "RUN" LED

        Serial.println(F("-> Emulator Running."));
      }
      //
      // Load SRAM from SPI
      //
      if ( rxFrame == ":LOADSPI") {
        lastEPROM = EEPROM.read(mem_cfg);
        load_SPIEEPROM(lastEPROM);
      }

      if ( rxFrame == ":ini16" ) {
        setBus(rom2kB);
        EEPROM.update(sram_cfg, rom2kB);
        if (saveSPI) {
          EEPROM.update(mem_cfg, rom2kB);
        }
      }
      if ( rxFrame == ":ini32" ) {
        setBus(rom4kB);
        EEPROM.update(sram_cfg, rom4kB);
        if (saveSPI) {
          EEPROM.update(mem_cfg, rom4kB);
        }
      }
      if ( rxFrame == ":ini64" ) {
        setBus(rom8kB);
        EEPROM.update(sram_cfg, rom8kB);
        if (saveSPI) {
          EEPROM.update(mem_cfg, rom8kB);
        }
      }
      if ( rxFrame == ":ini128" ) {
        setBus(rom16kB);
        EEPROM.update(sram_cfg, rom16kB);
        if (saveSPI) {
          EEPROM.update(mem_cfg, rom16kB);
        }
      }
      if ( rxFrame == ":ini256" ) {
        setBus(rom32kB);
        EEPROM.update(sram_cfg, rom32kB);
        if (saveSPI) {
          EEPROM.update(mem_cfg, rom32kB);
        }
      }
      if ( rxFrame == ":ini512" ) {
        setBus(rom64kB);
        EEPROM.update(sram_cfg, rom64kB);
        if (saveSPI) {
          EEPROM.update(mem_cfg, rom64kB);
        }
      }
      // data will be also written to SPI
      if ( rxFrame == ":iniSPI1" ) {
        saveSPI = true;
        EEPROM.update(save_cfg, 1);
        Serial.println(F("-> SPI save ON"));
      }
      // data will be also written to SPI
      if ( rxFrame == ":iniSPI0" ) {
        saveSPI = false;
        EEPROM.update(save_cfg, 0);
        Serial.println(F("-> SPI save OFF"));
      }
      //
      // process binary frame, new as of 2.0, process binary frame format <start address><bytecount><payload up to size of buffer> in chunks of 128Bytes
      //
      if ( rxFrame == ":SBN" ) {
        Serial.println(F("->in"));
        unsigned int startaddr = Serial.parseInt();
        unsigned int bytecount = Serial.parseInt();

        // now we know start address and how many bytes are coming
        int transfered = Serial.readBytes(byteBuffer, bytecount + 1); // may need bytecount + 1
        // now write the buffer to SRAM
        writeBuffer(startaddr, bytecount);
        if (saveSPI) {
          writeBufferSPI(startaddr, bytecount);
        }
        Serial.println(F("ACK"));
      }
      // load the SPI EEPROM data to SRAM on boot.
      if ( rxFrame == ":iniAuto1" ) {
        autoLoad = true;
        EEPROM.update(auto_cfg, 1);
        Serial.println(F("-> Auto Load ON"));
      }
      // data will be also written to SPI
      if ( rxFrame == ":iniAuto0" ) {
        autoLoad = false;
        EEPROM.update(auto_cfg, 0);
        Serial.println(F("-> Auto Load OFF"));
      }
      // Erase SPI EEPROM ( you can call it from Arduiono serial monitor by typing :SPICLR)
      if ( rxFrame == ":SPICLR" ) {
        clearSPIEEPROM();
        Serial.println(F("->ERASED SPI EEPROM"));
      }

      rxFrame = "";
    }
    else {
      rxFrame += ch;
    }
  }
} // end loop()

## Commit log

2021-01-01 BOM added
2021-01-01 BOM added & License changed
2021-01-08 PCB Release 1.2B
    [EPROM Emulator NG 2.GBL, EPROM Emulator NG 2.GBO, EPROM Emulator NG 2.GBP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]
2021-01-09 STL files for the housing added
    [Case Bottom for EPROM Emulator NG-II.stl, Case Top for EPROM Emulator NG-II.stl]
2021-01-28 Arduino Firmware V2.0rc3unified added"
2021-01-28 PCB Version 1.3 released
    [Bill of Materials-EPROM Emulator NG 2 V1.3.xlsx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]
2021-01-28 New pictures for release 1.3
    [Case Bottom for EPROM Emulator NG-II.stl, Case Top for EPROM Emulator NG-II.stl]
2021-01-28 Added description for PCB version 1.3.
2021-01-28 PCB order link added
